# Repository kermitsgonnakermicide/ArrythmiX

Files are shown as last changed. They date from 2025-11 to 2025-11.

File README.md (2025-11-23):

# Main Repo
This is the main repo for the Arryhtmix Project, which aims to develop a novel, end-to-end framework for
the prediction of caridiac events
>
> We have developed a novel end to end pipeline for the prediction of cardiac arrests through machine learning alongside a medical device to facilitate the collection of data for the model.
>
>The initial process takes place on the device. The single-lead AD8232 Sensor with integrated hardware high pass and low pass filters collects ECG Data from one lead with one electrode for common mode rejection. The data is read at a rate of 360 Hz by the nRF52840 using a 12-bit ADC and concurrently denoised through an integrated LSM6DS3. While the device is idle, it is kept in deep sleep mode, significantly reducing power consumption.
>Upon the collection of 10 data points, the buffer is dispatched using BLE to the host device.
>
>Upon being dispatched to the host device, two models are run on it. First, an Arrhythmia classification model based on the MIT-BIH dataset and architected with a BiLSTM and Random Forest classifier returns a dataclass which describes the type of arrhythmia if any. Secondly, a novel model based on the Sudden Cardiac Arrest Holter Database architected by DAKSH EXPLAIN HERE is implemented. This provides  a set of “risk classes” which give the probability of a heart attack happening in the specified timeframe. A f-score of 99 percent and of 85 percent is obtained from both models respectively.
> - ISEF Abstract
### Sections
- [Scripts](scripts)
  - scripts for interfacing and interaction with the device
- [Hardware](Hardware)
  - Device schematics, PCB Design etc.
- [Firmware](src)
  - firmware for the device
- [ML](ML)
  - machine learning stuff

### Images 
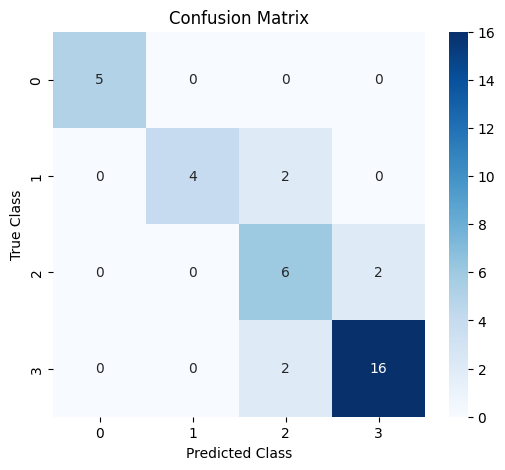
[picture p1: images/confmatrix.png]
confusion matrix

<br>
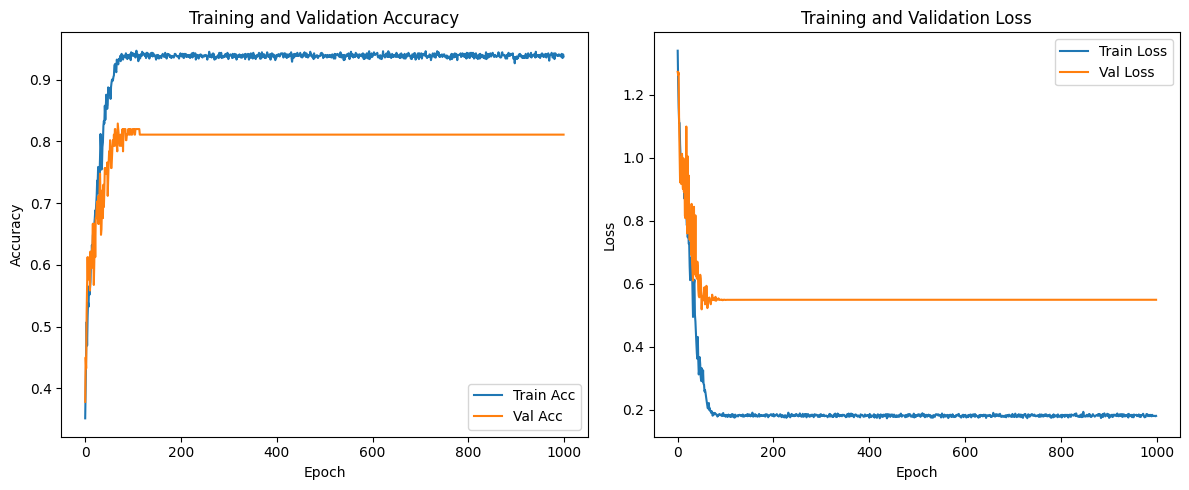
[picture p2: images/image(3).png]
train and vall graphs
    
<br>
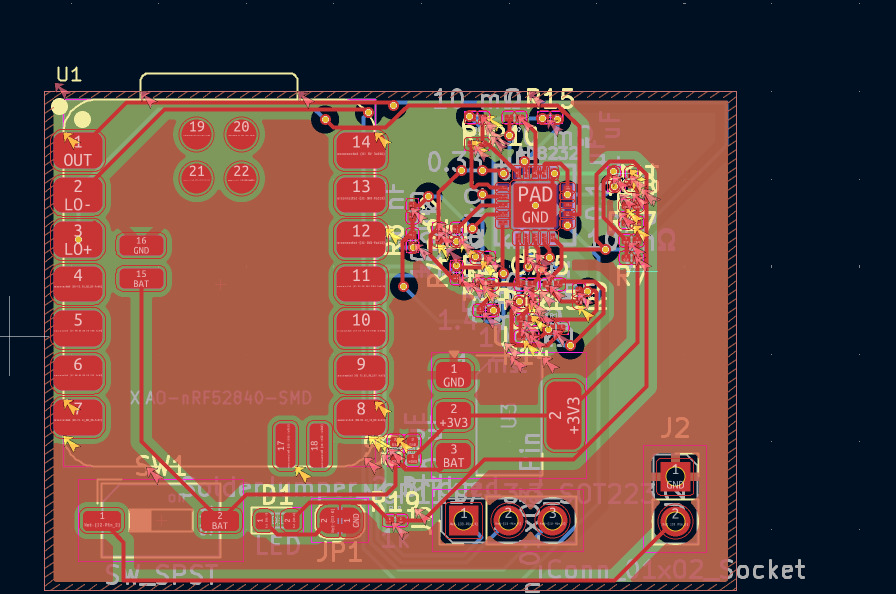
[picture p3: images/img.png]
routed PCB
    

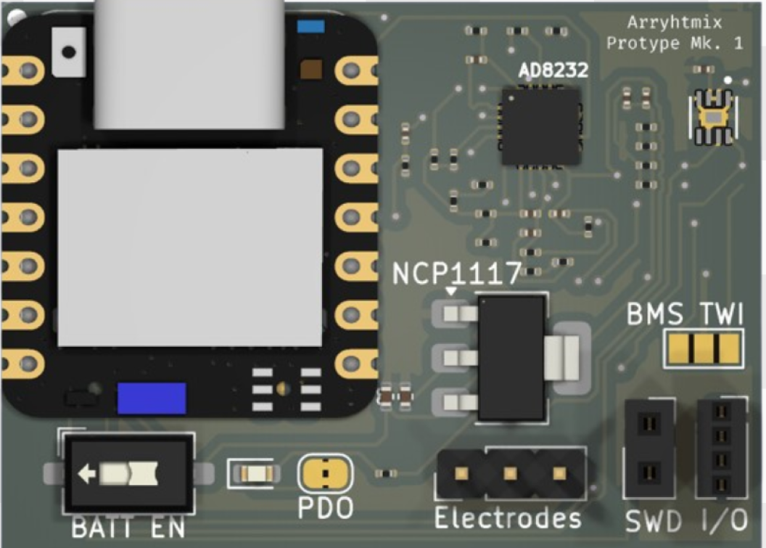
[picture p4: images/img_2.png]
 

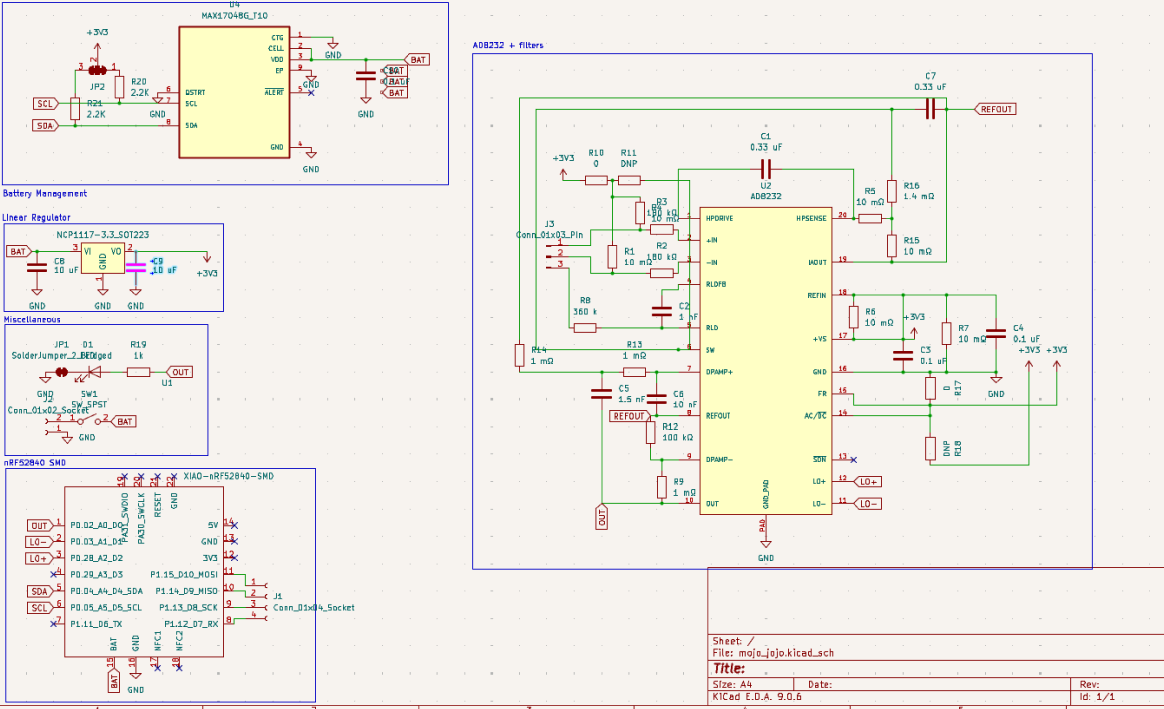
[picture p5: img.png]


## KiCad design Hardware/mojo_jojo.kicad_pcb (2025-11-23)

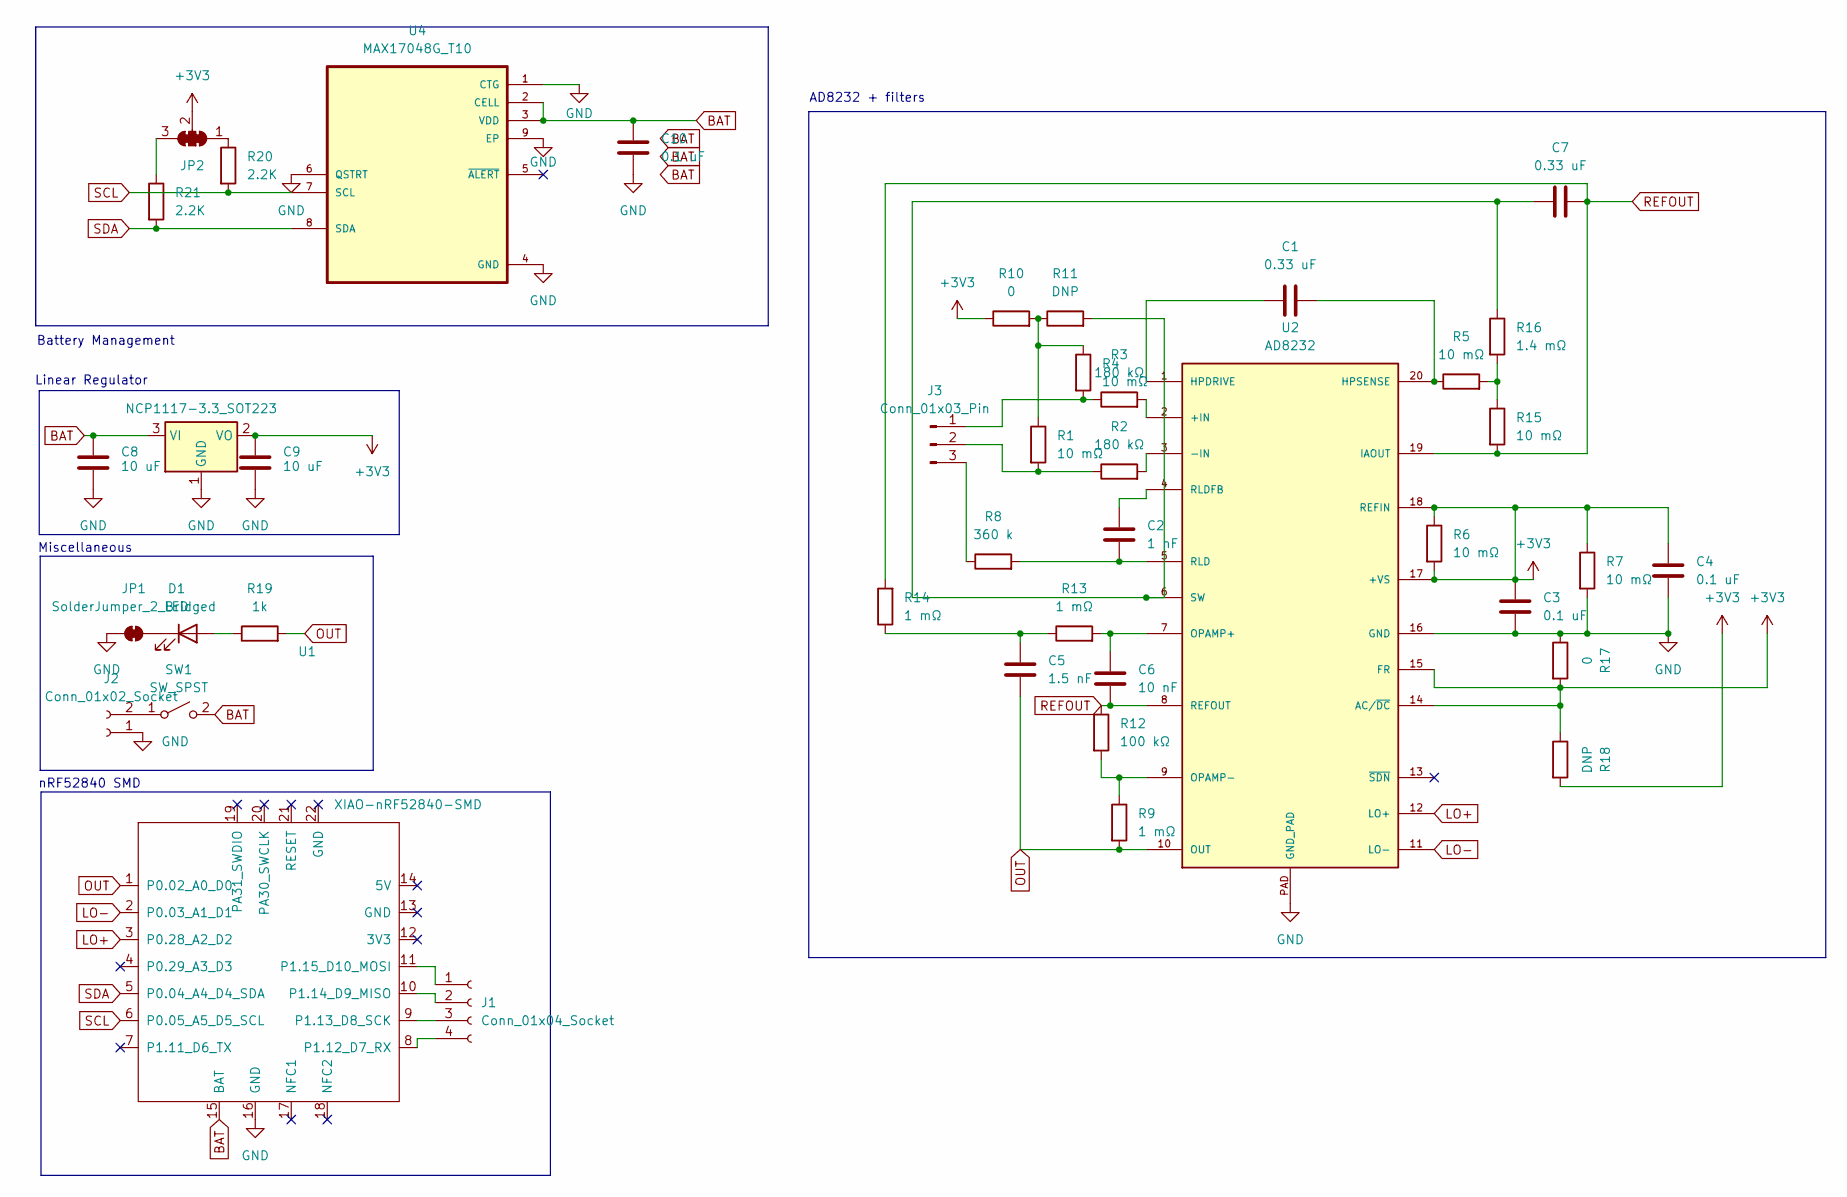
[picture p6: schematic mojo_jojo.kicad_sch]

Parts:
C1, C7: 0.33 uF; C_0201_0603Metric
C2: 1 nF; C_0201_0603Metric
C3, C4, C10: 0.1 uF; C_0201_0603Metric
C5: 1.5 nF; C_0201_0603Metric
C6: 10 nF; C_0201_0603Metric
C8, C9: 10 uF; C_0402_1005Metric
D1: LED; LED_0603_1608Metric
J1: Conn_01x04_Socket; PinSocket_1x04_P1.27mm_Vertical
J2: Conn_01x02_Socket; PinSocket_1x02_P2.54mm_Vertical
J3: Conn_01x03_Pin; PinHeader_1x03_P2.54mm_Vertical
JP1: SolderJumper_2_Bridged; SolderJumper-2_P1.3mm_Bridged2Bar_RoundedPad1.0x1.5mm
JP2: SolderJumper_3_Bridged123; SolderJumper-3_P1.3mm_Open_Pad1.0x1.5mm_NumberLabels
R1, R4, R5, R6, R7, R15: 10 mΩ; R_0201_0603Metric
R2, R3: 180 kΩ; R_0201_0603Metric
R8: 360 k; R_0201_0603Metric
R9, R13, R14: 1 mΩ; R_0201_0603Metric
R10, R17: 0; R_0201_0603Metric
R11, R18: DNP; R_0201_0603Metric
R12: 100 kΩ; R_0201_0603Metric
R16: 1.4 mΩ; R_0201_0603Metric
R19: 1k; R_0201_0603Metric
R20, R21: 2.2K; R_0402_1005Metric
SW1: SW_SPST; SW_DIP_SPSTx01_Slide_6.7x4.1mm_W6.73mm_P2.54mm_LowProfile_J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
U1: XIAO-nRF52840-SMD
U2: AD8232; LFCSP_20
U3: NCP1117-3.3_SOT223; SOT-223-3_TabPin2
U4: MAX17048G_T10; SON50P200X200X80-9N

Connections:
+3V3: C3.2, C4.2, C9.1, JP2.2 (C), R6.1, R6.2, R7.1, R10.1, R17.2, R18.1, R18.2, U2.14 (AC/~DC), U2.15 (FR), U2.17 (+VS), U2.18 (REFIN), U3.2 (VO); also elsewhere on the board
BAT: C8.1, C10.2, SW1.2 (B), U1.15 (BAT), U3.3 (VI), U4.2 (CELL), U4.3 (VDD)
GND: C3.1, C4.1, C8.2, C9.2, C10.1, J2.1, JP1.1 (A), R7.2, R17.1, U1.16 (GND), U2.16 (GND), U2.PAD (GND_PAD), U3.1 (GND), U4.1 (CTG), U4.4 (GND), U4.6 (QSTRT), U4.9 (EP); also elsewhere on the board
LO+: U1.3 (P0.28_A2_D2), U2.12 (LO+)
LO-: U1.2 (P0.03_A1_D1), U2.11 (LO-)
unnamed: C5.2, R13.1, R14.1
unnamed: D1.2 (A), R19.1
unnamed 7: D1.1 (K), JP1.2 (B); also elsewhere on the board
unnamed: J1.1, U1.11 (P1.15_D10_MOSI)
unnamed: J1.2, U1.10 (P1.14_D9_MISO)
unnamed: J1.3, U1.9 (P1.13_D8_SCK)
unnamed: J1.4, U1.8 (P1.12_D7_RX)
unnamed: J2.2, SW1.1 (A)
unnamed: J3.1, R3.1, R4.2
unnamed: J3.2, R1.2, R2.1
unnamed: J3.3, R8.1
unnamed: JP2.1 (A), R20.1
unnamed: JP2.3 (B), R21.1
unnamed: R1.1, R4.1, R10.2, R11.1
unnamed: R5.2, R15.1, R16.2
unnamed: R3.2, U2.2 (+IN)
unnamed: R2.2, U2.3 (-IN)
unnamed: C1.1, U2.1 (HPDRIVE)
unnamed: C1.2, R5.1, U2.20 (HPSENSE)
unnamed: C6.2, R13.2, U2.7 (OPAMP+)
unnamed: R9.1, R12.2, U2.9 (OPAMP-)
unnamed: C2.2, R8.2, U2.5 (RLD)
unnamed: C2.1, U2.4 (RLDFB)
unnamed: C7.1, R11.2, R16.1, U2.6 (SW)
OUT: C5.1, R9.2, R19.2, U1.1 (P0.02_A0_D0), U2.10 (OUT)
REFOUT: C6.1, C7.2, R12.1, R14.2, R15.2, U2.8 (REFOUT), U2.19 (IAOUT)
SCL: R20.2, U1.6 (P0.05_A5_D5_SCL), U4.7 (SCL)
SDA: R21.2, U1.5 (P0.04_A4_D4_SDA), U4.8 (SDA)

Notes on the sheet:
nRF52840 SMD
AD8232 + filters
Miscellaneous
Linear Regulator
Battery Management

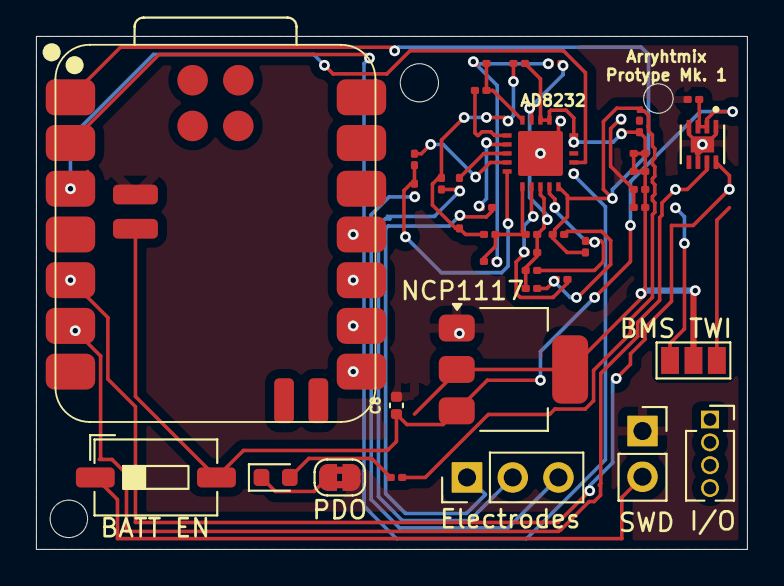
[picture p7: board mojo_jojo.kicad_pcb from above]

Board: 4 copper layers, 39.5 x 28.5 mm, 40 parts (1 on the bottom side), 31 nets.

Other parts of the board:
BMS TWI: SolderJumper_3_Bridged123; SolderJumper-3_P1.3mm_Open_Pad1.0x1.5mm_NumberLabels
PDO: SolderJumper_2_Bridged; SolderJumper-2_P1.3mm_Bridged2Bar_RoundedPad1.0x1.5mm

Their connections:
+3V3: BMS TWI.2 (C); also elsewhere on the board
GND: PDO.1 (A); also elsewhere on the board
unnamed 7: PDO.2 (B); also elsewhere on the board

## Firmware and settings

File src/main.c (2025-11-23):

#include <zephyr/kernel.h>
#include <zephyr/device.h>
#include <zephyr/logging/log.h>
#include <zephyr/bluetooth/bluetooth.h>
#include <zephyr/bluetooth/hci.h>
#include <zephyr/bluetooth/conn.h>
#include <zephyr/bluetooth/uuid.h>
#include <zephyr/bluetooth/gatt.h>
#include <zephyr/devicetree.h>
#include <zephyr/drivers/gpio.h>
#include <zephyr/drivers/adc.h>
LOG_MODULE_REGISTER(ecg_app, LOG_LEVEL_INF);
#define ECG_SERVICE_UUID_VAL \
    BT_UUID_128_ENCODE(0x12345678, 0x1234, 0x5678, 0x1234, 0x56789abcdef0)
#define ECG_CHAR_UUID_VAL \
    BT_UUID_128_ENCODE(0x12345678, 0x1234, 0x5678, 0x1234, 0x56789abcdef1)

static struct bt_uuid_128 ecg_service_uuid = BT_UUID_INIT_128(ECG_SERVICE_UUID_VAL);
static struct bt_uuid_128 ecg_char_uuid = BT_UUID_INIT_128(ECG_CHAR_UUID_VAL);

static bool notify_enabled = false;
static void ecg_ccc_cfg_changed(const struct bt_gatt_attr *attr, uint16_t value)
{
    notify_enabled = (value == BT_GATT_CCC_NOTIFY);
    LOG_INF("ECG notifications %s", notify_enabled ? "enabled" : "disabled");
}
#define DATA_LENGTH 20
static uint16_t ecg_data[DATA_LENGTH];
BT_GATT_SERVICE_DEFINE(ecg_service,
    BT_GATT_PRIMARY_SERVICE(&ecg_service_uuid),
    BT_GATT_CHARACTERISTIC(&ecg_char_uuid.uuid,
                          BT_GATT_CHRC_NOTIFY,
                          BT_GATT_PERM_NONE,
                          NULL, NULL, NULL),
    BT_GATT_CCC(ecg_ccc_cfg_changed,
               BT_GATT_PERM_READ | BT_GATT_PERM_WRITE),
);

static const struct bt_data ad[] = {
    BT_DATA_BYTES(BT_DATA_FLAGS, (BT_LE_AD_GENERAL | BT_LE_AD_NO_BREDR)),
    BT_DATA_BYTES(BT_DATA_UUID128_ALL, ECG_SERVICE_UUID_VAL),
};

static const struct gpio_dt_spec lo_pos = GPIO_DT_SPEC_GET(DT_ALIAS(leads_pos), gpios);
static const struct gpio_dt_spec lo_neg = GPIO_DT_SPEC_GET(DT_ALIAS(leads_negative), gpios);
static const struct adc_dt_spec ecg_adc = ADC_DT_SPEC_GET_BY_IDX(DT_PATH(zephyr_user), 0);

struct k_timer send_timer;
struct k_work send_work;
int lo_neg_state, lo_pos_state;
uint8_t cursor_pos = 0;
uint16_t adc_raw_value;
struct adc_sequence sequence;
void send_work_handler(struct k_work *work)
{
    lo_neg_state = gpio_pin_get_dt(&lo_neg);
    lo_pos_state = gpio_pin_get_dt(&lo_pos);
    
    if (cursor_pos >= DATA_LENGTH) {
        if (notify_enabled) {
            struct bt_gatt_attr *attr = bt_gatt_find_by_uuid(ecg_service.attrs, 
                                                             ecg_service.attr_count,
                                                             &ecg_char_uuid.uuid);
            if (attr) {
                bt_gatt_notify(NULL, attr, ecg_data, sizeof(ecg_data));
            }
        }
        cursor_pos = 0;
        return;
    }
    
    if (lo_neg_state && lo_pos_state) {
        LOG_INF("leads off");
        ecg_data[cursor_pos++] = 0;
    } else {
        adc_read(ecg_adc.dev, &sequence);
        ecg_data[cursor_pos++] = adc_raw_value;
    }
}

void timer_expiry(struct k_timer *timer_id)
{
    k_work_submit(&send_work);
}

static void connected(struct bt_conn *conn, uint8_t err)
{
    if (err) {
        LOG_ERR("Connection failed (err 0x%02x)", err);
    } else {
        LOG_INF("Connected");
    }
}

static void disconnected(struct bt_conn *conn, uint8_t reason)
{
    LOG_INF("Disconnected (reason 0x%02x)", reason);
}

BT_CONN_CB_DEFINE(conn_callbacks) = {
    .connected = connected,
    .disconnected = disconnected,
};

int main(void)
{
    int err, ret;

    err = bt_enable(NULL);
    if (err) {
        LOG_ERR("Bluetooth init failed (err %d)", err);
        return -1;
    }
    LOG_INF("Bluetooth initialized");

    if (!gpio_is_ready_dt(&lo_pos) || !gpio_is_ready_dt(&lo_neg)) {
        LOG_ERR("GPIO driver not ready");
        return -1;
    }

    if (!adc_is_ready_dt(&ecg_adc)) {
        LOG_ERR("ADC driver not ready");
        return -1;
    }

    ret = gpio_pin_configure_dt(&lo_pos, GPIO_INPUT);
    if (ret < 0) {
        LOG_ERR("Failed to configure lo_pos");
        return -1;
    }

    ret = gpio_pin_configure_dt(&lo_neg, GPIO_INPUT);
    if (ret < 0) {
        LOG_ERR("Failed to configure lo_neg");
        return -1;
    }
    ret = adc_channel_setup_dt(&ecg_adc);
    if (ret < 0) {
        LOG_ERR("ADC channel setup failed");
        return -1;
    }
    ret = adc_sequence_init_dt(&ecg_adc, &sequence);
    if (ret < 0) {
        LOG_ERR("ADC sequence init failed");
        return -1;
    }

    sequence.buffer = &adc_raw_value;
    sequence.buffer_size = sizeof(adc_raw_value);

    k_work_init(&send_work, send_work_handler);
    k_timer_init(&send_timer, timer_expiry, NULL);
    k_timer_start(&send_timer, K_USEC(2300), K_USEC(2300));

    err = bt_le_adv_start(BT_LE_ADV_CONN_FAST_1, ad, ARRAY_SIZE(ad), NULL, 0);
    if (err) {
        LOG_ERR("Advertising failed to start (err %d)", err);
        return -1;
    }
    LOG_INF("Advertising started");

    while (1) {
        k_sleep(K_FOREVER);
    }

    return 0;
}

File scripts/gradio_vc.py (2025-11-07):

# gradio_ecg_infer.py
import threading
import time
from collections import deque
import matplotlib.pyplot as plt
import numpy as np
import gradio as gr
import simplepyble
from ml.runner import predictor  # your predictor class
import random

# === Configuration ===
MAX_POINTS = 200                 # points shown on plot (sliding window)
PLOT_RANGE = (0, 4)              # y-axis limits (V)
SERVICE_UUID = "0000180d-0000-1000-8000-00805f9b34fb"
CHARACTERISTIC_UUID = "e2fd985e-ceb8-4ccb-9cd3-52563e4b5c62"
DEVICE_IDENTIFIER = "ECG Data"
REFERENCE_VOLTAGE = 3.7
SCAN_DURATION = 5000             # ms for simplepyble.scan_for
INFERENCE_TRIGGER_COUNT = 40     # run inference every N new samples
INFERENCE_WINDOW_SIZE = 171      # samples to send to predictor (it will resample if needed)
PLOT_UPDATE_INTERVAL = 0.3       # seconds between UI plot updates

# === Shared state / concurrency primitives ===
plot_lock = threading.Lock()
inference_lock = threading.Lock()
stop_event = threading.Event()

plot_buffer = deque([0.0] * MAX_POINTS, maxlen=MAX_POINTS)
inference_buffer = deque(maxlen=INFERENCE_WINDOW_SIZE)

# Predictor (loads model inside its __init__)
predictor_obj = predictor(INFERENCE_WINDOW_SIZE)

# last prediction (protected by inference_lock)
_last_prediction = "N/A"

# Device handle
ecg_device = None


# ---------------- BLE / Simulated Feed ----------------
def ble_notification_callback(received_bytes):
    """Callback from simplepyble notifications."""
    global _last_prediction
    if stop_event.is_set():
        return
    try:
        if received_bytes == b"Leads Off":
            # optional: you could set a status variable
            return
        adc_value = float(received_bytes.decode("utf-8").strip())
        voltage = (adc_value / 1024.0) * REFERENCE_VOLTAGE
    except Exception:
        return

    with plot_lock:
        plot_buffer.append(voltage)
    with inference_lock:
        inference_buffer.append(voltage)


def ble_feed_thread_func(peripheral):
    """Keeps the BLE subscription alive. Notification callback appends data."""
    try:
        peripheral.notify(SERVICE_UUID, CHARACTERISTIC_UUID, ble_notification_callback)
        # Keep thread alive while connected and not stopped
        while not stop_event.is_set() and peripheral.is_connected():
            time.sleep(0.2)
    except Exception:
        pass
    finally:
        try:
            if peripheral.is_connected():
                peripheral.disconnect()
        except Exception:
            pass


def scan_and_connect_device():
    """Scan for device and connect. Returns connected peripheral or None."""
    adapters = simplepyble.Adapter.get_adapters()
    if not adapters:
        print("No Bluetooth adapters found.")
        return None
    adapter = adapters[0]
    print(f"Using adapter: {adapter.identifier()} [{adapter.address()}]")
    print(f"Scanning for devices for {SCAN_DURATION} ms...")
    adapter.scan_for(SCAN_DURATION)
    peripherals = adapter.scan_get_results()
    for p in peripherals:
        print(f"Found: {p.identifier()} [{p.address()}]")
        if p.identifier() == DEVICE_IDENTIFIER:
            try:
                print(f"Connecting to {p.identifier()}...")
                p.connect()
                print("Connected.")
                return p
            except Exception as e:
                print(f"Failed to connect: {e}")
                return None
    print("Target device not found.")
    return None


def simulated_feed_thread_func(rate_hz=20):
    """Generate an ECG-like waveform with noise and occasional pulses."""
    t = 0.0
    dt = 1.0 / rate_hz
    while not stop_event.is_set():
        # synthetic ECG-like baseline + QRS-like spikes
        baseline = 1.8 + 0.2 * np.sin(2 * np.pi * 1.0 * t)  # slow baseline wander
        qrs = 0.0
        # occasional spike pattern
        if random.random() < 0.02:
            qrs = 1.0 + 0.5 * random.random()
        noise = 0.05 * np.random.randn()
        voltage = float(np.clip(baseline + qrs + noise, 0.0, 4.0))
        with plot_lock:
            plot_buffer.append(voltage)
        with inference_lock:
            inference_buffer.append(voltage)
        t += dt
        time.sleep(dt)


# ---------------- Inference worker ----------------
def inference_worker_func():
    """Runs in background. When enough data in inference_buffer, runs predictor.get_prediction on a copy."""
    global _last_prediction
    while not stop_event.is_set():
        # wait a tiny bit
        time.sleep(0.05)
        # Trigger only if we have enough samples (or you can always run on whatever is present)
        should_run = False
        with inference_lock:
            cur_len = len(inference_buffer)
            if cur_len >= 10:  # minimal useful size
                # Run inference every INFERENCE_TRIGGER_COUNT new samples
                # Use a simple policy: run if buffer length increased by trigger count OR every fixed interval
                # For simplicity: run if len >= INFERENCE_WINDOW_SIZE OR random small chance to avoid lockstep
                if cur_len >= INFERENCE_WINDOW_SIZE or cur_len % INFERENCE_TRIGGER_COUNT == 0:
                    data_for_infer = list(inference_buffer)
                    should_run = True
                else:
                    should_run = False
        if should_run:
            try:
                # Predictor will resample internally to the required length
                pred = predictor_obj.get_prediction(data_for_infer)
                with inference_lock:
                    _last_prediction = pred
            except Exception as e:
                with inference_lock:
                    _last_prediction = f"Error: {e}"


# ---------------- Plot generator for Gradio streaming ----------------
def make_ecg_figure():
    with plot_lock:
        y = list(plot_buffer)
    fig, ax = plt.subplots(figsize=(8, 3))
    ax.plot(range(len(y)), y, color="red")
    ax.set_ylim(PLOT_RANGE)
    ax.set_xlim(0, MAX_POINTS - 1)
    ax.set_xlabel("Samples")
    ax.set_ylabel("Voltage (V)")
    ax.set_title(f"Live ECG (mean={np.mean(y):.2f} V)")
    ax.grid(True)
    fig.tight_layout()
    return fig


def stream_plot_and_pred():
    """Generator that yields (figure, prediction_text) tuples for gradio.load streaming."""
    while not stop_event.is_set():
        fig = make_ecg_figure()
        with inference_lock:
            pred = _last_prediction
        yield (fig, pred)
        time.sleep(PLOT_UPDATE_INTERVAL)
    # final yield once to let UI settle
    fig = make_ecg_figure()
    with inference_lock:
        pred = _last_prediction
    yield (fig, pred)
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

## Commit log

2025-11-07 sleep instead of busy waiting for better power consumption, need to transmit IMU
2025-11-19 adc readring
2025-11-23 add pcb files
    [mojo_jojo.kicad_pcb, mojo_jojo.kicad_sch]
